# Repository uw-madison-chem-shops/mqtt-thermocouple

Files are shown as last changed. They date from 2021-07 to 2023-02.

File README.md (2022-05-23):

# MQTT thermocouple

Simple project for getting thermocouple sensors online using MQTT.

Designed to work with [mqtt.chem.wisc.edu](https://mqtt.chem.wisc.edu/).

## Repository

This is an open source hardware project licensed under the CERN Open Hardware Licence Version 2 - Permissive.
Please see the LICENSE file for the complete license.

This repository is being mirrored to several version control systems in an attempt to ensure maximum avaliability.

| name | url |
| --- | --- |
| GitHub (primary) | https://github.com/uw-madison-chem-shops/mqtt-thermocouple |
| GitLab | https://gitlab.com/uw-madison-chem-shops/mqtt-thermocouple |

## PCB

This PCB was designed using KiCAD version 5.
Refer to `mqtt-thermocouple.pdf` for schematic.
Refer to `mqtt-thermocouple.csv` for bill of materials.
PCB images generated with [tracespace](https://github.com/tracespace/tracespace) follow.




## Firmware

This project uses [micropython](https://micropython.org/), specifically [microhomie](https://github.com/microhomie/microhomie).
Refer to the "firmware" directory in this repository for detailed instructions.

## Changelog

### Unprinted

### B

#### added
- oshw logo
- github link

#### fixed
- resized holes for mounting piece
- added i2c pull up resistors

### A

#### Added
- initial design

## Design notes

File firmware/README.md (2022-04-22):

# mqtt-weather-station firmware

This project uses [micropython](https://micropython.org/), specifically [microhomie](https://github.com/microhomie/microhomie). Currently we build on microhomie-esp8266-v3.0.2, the binary is in the folder.

You must define the private information defined in `settings.py`. Copy `settings.py.example` to make a folder `settings.py` and define all relevant variables.

Run `flash.sh` to flash the board. You will need [esptool](https://github.com/espressif/esptool) and [ampy](https://github.com/scientifichackers/ampy).

We recommend an [FTDI Basic Breakout](https://www.sparkfun.com/products/9716) to physically program the ESP8266.

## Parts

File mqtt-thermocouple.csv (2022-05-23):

Source: | /home/blaise/source/uw-madison-chem-shops/mqtt-thermocouple/kicad/mqtt-thermocouple.kicad_sch
Date: | Mon 23 May 2022 12:01:26 PM CDT
Tool: | Eeschema 6.0.5+dfsg-1
Generator: | /usr/share/kicad/plugins/bom_csv_grouped_by_value_with_fp.py
Component Count: | 32
Ref | Qnty | Value | Cmp name | Footprint | Description | Vendor
A1, | 1 | Adafruit_HUZZAH_ESP8266_breakout | Adafruit_HUZZAH_ESP8266_breakout | Module:Adafruit_HUZZAH_ESP8266_breakout | 32-bit microcontroller module with WiFi
C1, | 1 | 100u | CP1 | Capacitor_THT:CP_Radial_Tantal_D7.0mm_P2.50mm
C2, | 1 | 10u | C | Capacitor_SMD:C_1206_3216Metric_Pad1.33x1.80mm_HandSolder | Unpolarized capacitor
C3, | 1 | 22u | C | Capacitor_SMD:C_1206_3216Metric_Pad1.33x1.80mm_HandSolder | Unpolarized capacitor
C4, C5, | 2 | 1u | C | Capacitor_SMD:C_1206_3216Metric_Pad1.33x1.80mm_HandSolder | Unpolarized capacitor
C6, | 1 | 100n | C | Capacitor_SMD:C_1206_3216Metric_Pad1.33x1.80mm_HandSolder | Unpolarized capacitor
C7, | 1 | 20p | C | Capacitor_SMD:C_1206_3216Metric_Pad1.33x1.80mm_HandSolder | Unpolarized capacitor
D1, D2, | 2 | LED | LED | LED_SMD:LED_1206_3216Metric_Pad1.42x1.75mm_HandSolder | Light emitting diode
D3, D4, D5, D6, | 4 | ACSC02-41SURKWA-F01 | ACSC02-41SURKWA-F01 | footprints:ACSC02-41SURKWA-F01
J1, | 1 | Barrel_Jack | Barrel_Jack | Connector_BarrelJack:BarrelJack_Horizontal | DC Barrel Jack
PS1, | 1 | VXO7805-500-M | VXO7805-500-M | CONV_VXO7805-500-M
Q1, Q2, | 2 | 2N7000 | Q_NMOS_GSD | Package_TO_SOT_SMD:SOT-23_Handsoldering | N-MOSFET transistor, gate/source/drain
R1, R2, | 2 | 1k | R_US | Resistor_SMD:R_1206_3216Metric_Pad1.30x1.75mm_HandSolder | Resistor, US symbol
R3, | 1 | 100k | R_US | Resistor_SMD:R_1206_3216Metric_Pad1.30x1.75mm_HandSolder | Resistor, US symbol
R4, R7, R8, R10, | 4 | 4.7k | R_US | Resistor_SMD:R_1206_3216Metric_Pad1.30x1.75mm_HandSolder | Resistor, US symbol
R5, | 1 | 470k | R_US | Resistor_SMD:R_1206_3216Metric_Pad1.30x1.75mm_HandSolder | Resistor, US symbol
R6, R9, | 2 | 1M | R_US | Resistor_SMD:R_1206_3216Metric_Pad1.30x1.75mm_HandSolder | Resistor, US symbol
TC1, | 1 | Thermocouple | Thermocouple | footprints:K1X-FEMX-CON-FP-X-PCCX | Thermocouple
U1, | 1 | MCP9600-E_MX | MCP9600-E_MX | footprints:MX
U2, | 1 | CD4060BM96 | CD4060BM96 | Package_SO:SOIC-16_3.9x9.9mm_P1.27mm
U3, | 1 | MAX6951 | MAX6951 | Package_SO:QSOP-16_3.9x4.9mm_P0.635mm

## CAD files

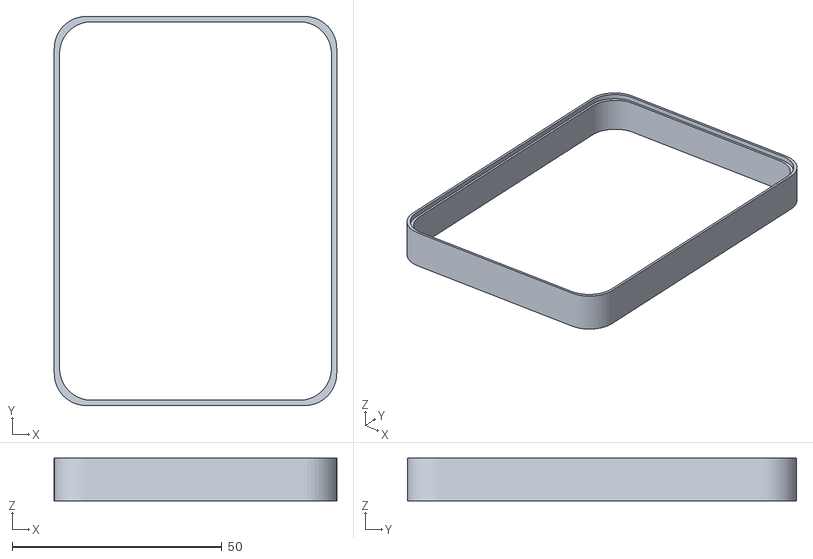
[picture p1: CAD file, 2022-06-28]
adapter-plate/potting-bracket.stl
67.3 x 92.7 x 10.2

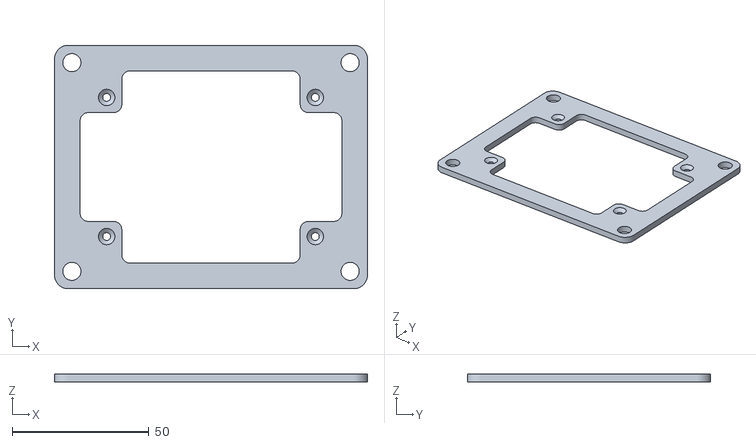
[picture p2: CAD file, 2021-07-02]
adapter-plate/adapter-plate.stl
114.3 x 88.9 x 3.00

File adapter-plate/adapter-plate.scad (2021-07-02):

$fn=50;
inch = 25.4;

module roundedRect(size, radius)
{
        x = size[0];
        y = size[1];
        z = size[2];

        linear_extrude(height=z)
        hull()
        {
                // place 4 circles in the corners, with the given radius
                translate([(-x/2)+radius, (-y/2)+radius, 0])
                circle(r=radius);

                translate([(x/2)-radius, (-y/2)+radius, 0])
                circle(r=radius);

                translate([(-x/2) + radius, (y/2)-radius, 0])
                circle(r=radius);

                translate([(x/2)-radius, (y/2)-radius, 0])
                circle(r=radius);
        }

}

module counterSunk(position, radius)
{
union()
    {
     translate(position)
     union()
        {
     cylinder(3, radius, radius, 8, center=false);
     cylinder(3, 0, 3, center=false);
        }
    }
    
}

difference()
{
roundedRect([4.5*inch, 3.5*inch, 3], 5, center=false);

translate([-4*inch/2, -3*inch/2, 0])
cylinder(3, 0.13*inch, 0.13*inch, 8, center=false);
    
translate([-4*inch/2, 3*inch/2, 0])
cylinder(3, 0.13*inch, 0.13*inch, 8, center=false);
    
translate([4*inch/2, -3*inch/2, 0])
cylinder(3, 0.13*inch, 0.13*inch, 8, center=false);
    
translate([4*inch/2, 3*inch/2, 0])
cylinder(3, 0.13*inch, 0.13*inch, 8, center=false);

counterSunk([3*inch/2, 2*inch/2, 0], 0.056*inch);
counterSunk([-3*inch/2, 2*inch/2, 0], 0.056*inch);
counterSunk([3*inch/2, -2*inch/2, 0], 0.056*inch);
counterSunk([-3*inch/2, -2*inch/2, 0], 0.056*inch);



linear_extrude(height=5)
offset(r=3){
offset(r=-6){
union(){
square([4*inch,1.8*inch], center=true);
square([2.8*inch,3*inch], center=true);
}
}
}
}

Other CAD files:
adapter-plate/potting-bracket.scad

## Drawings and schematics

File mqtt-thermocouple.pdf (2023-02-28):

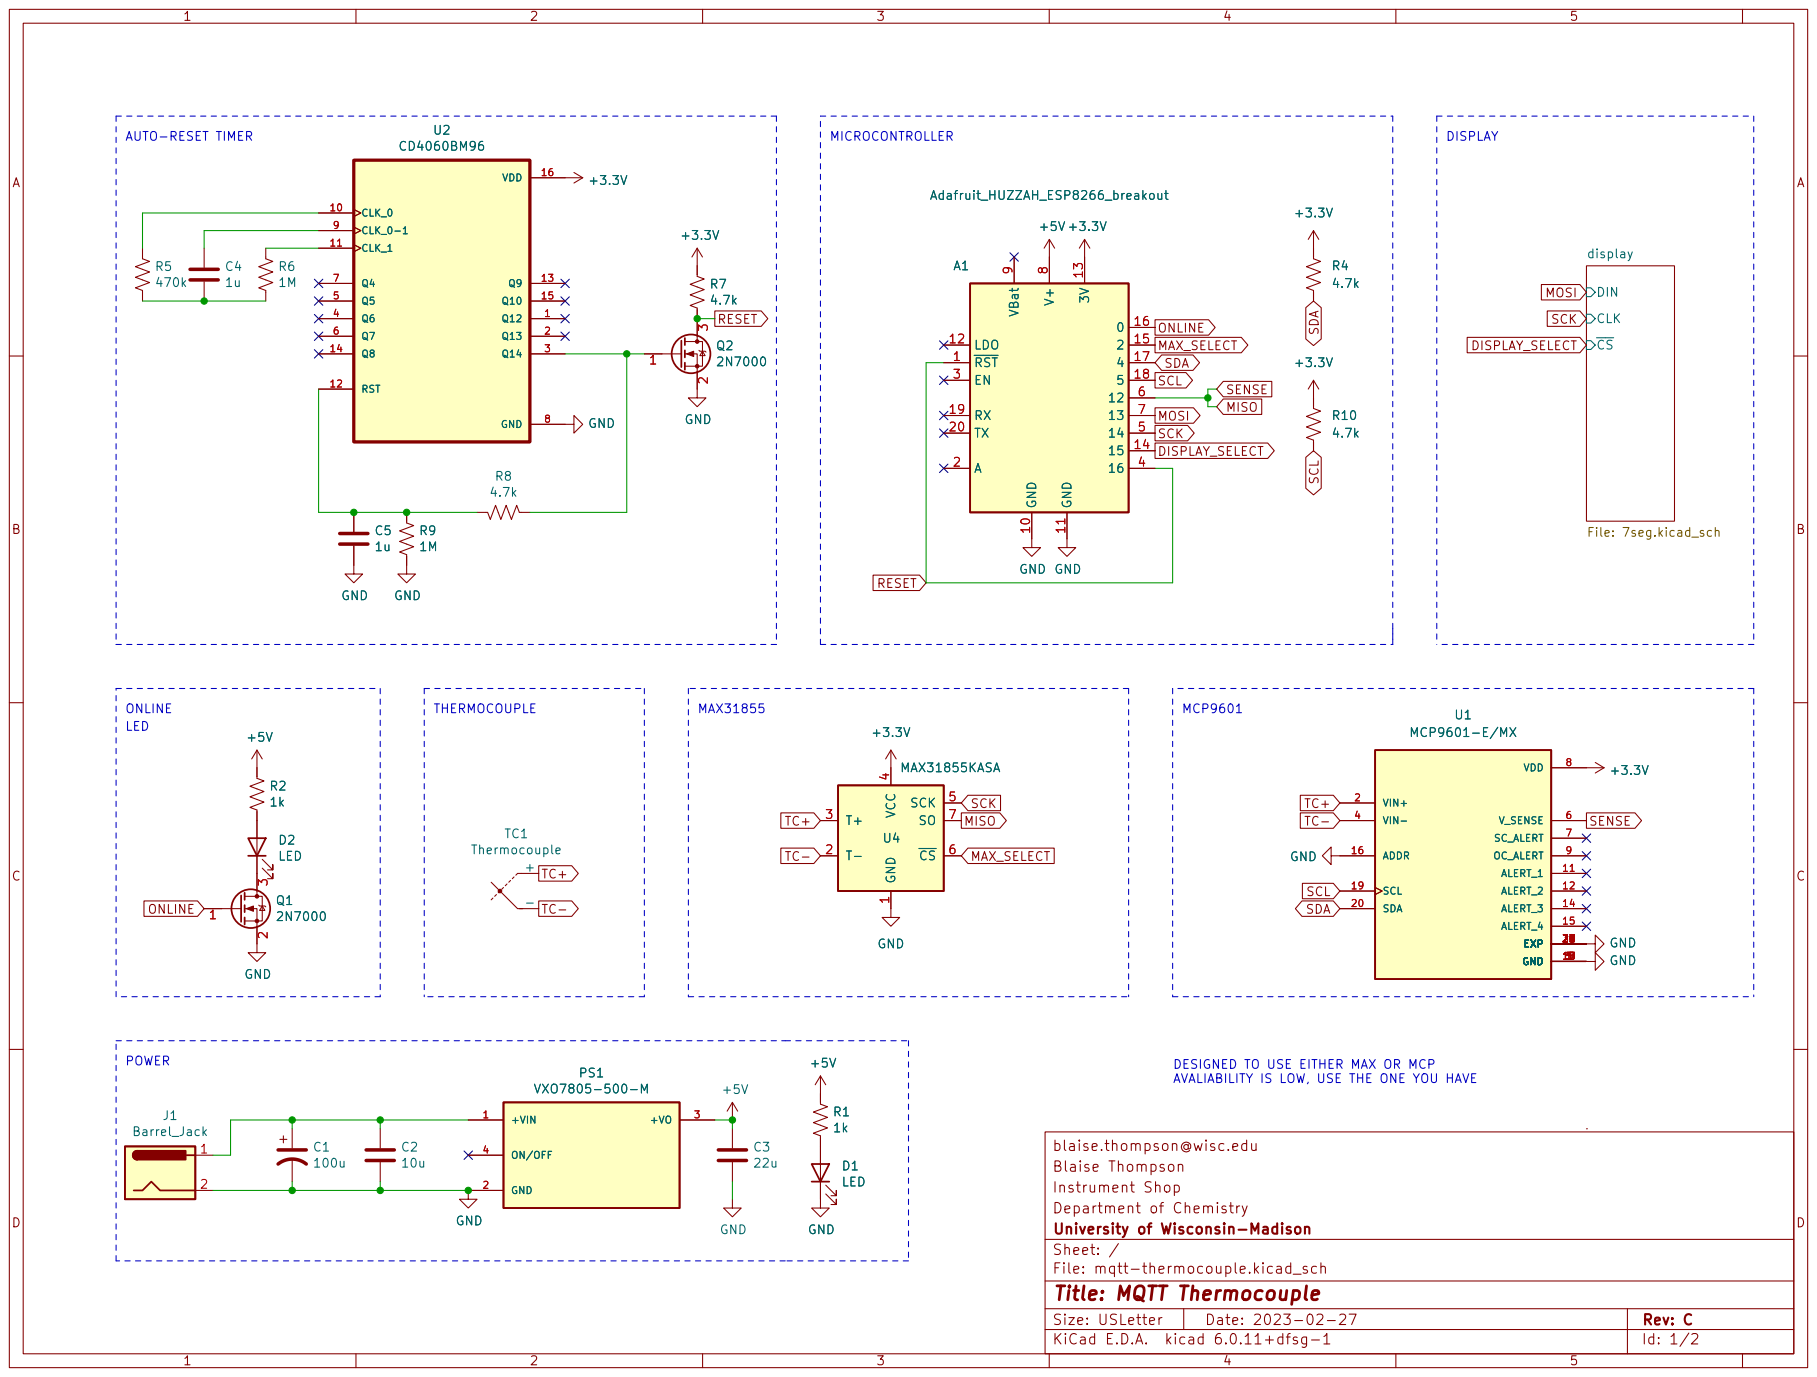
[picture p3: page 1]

4 SCK 5 ~{CS}6 SO 7 U4 MAX31855KASA GND GND

4 SCK 5 ~{CS}6 SO 7 GND

AVALIABILITY IS LOW, USE THE ONE YOU HAVE

blaise.thompson@wisc.edu

Id: 1/2 Title: MQTT Thermocouple

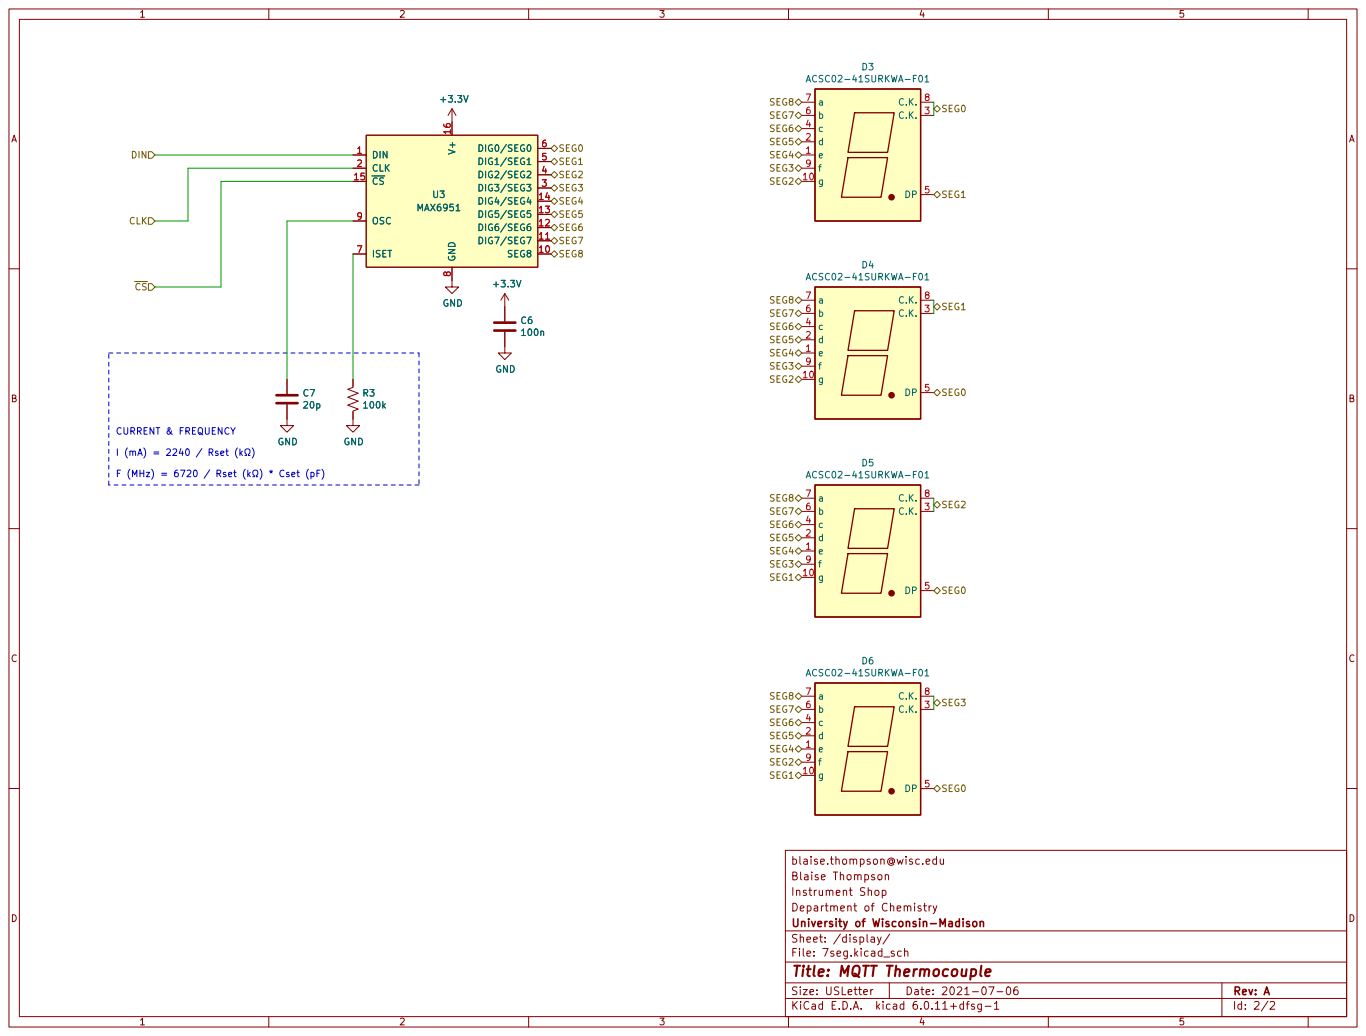
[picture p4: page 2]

File: 7seg.kicad_sch Sheet: /display/
Id: 2/2 Title: MQTT Thermocouple

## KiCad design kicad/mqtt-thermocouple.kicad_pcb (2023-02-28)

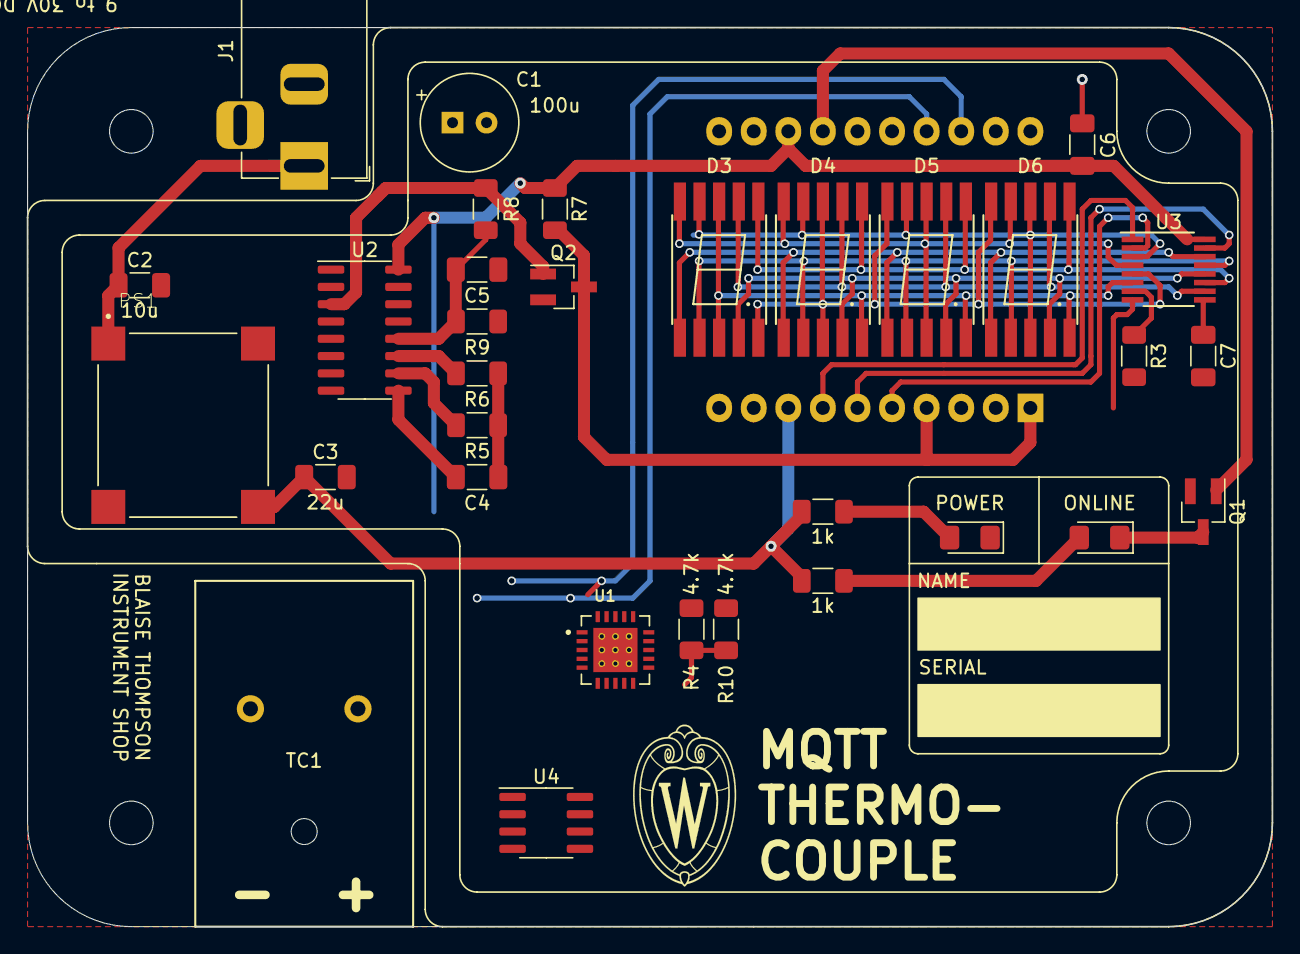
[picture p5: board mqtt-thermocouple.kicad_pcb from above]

Board: 2 copper layers, 91.4 x 66.0 mm, 33 parts (1 on the bottom side), 33 nets.

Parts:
A1: Adafruit_HUZZAH_ESP8266_breakout
C1: 100u; CP_Radial_Tantal_D7.0mm_P2.50mm
C2: 10u; C_1206_3216Metric_Pad1.33x1.80mm_HandSolder
C3: 22u; C_1206_3216Metric_Pad1.33x1.80mm_HandSolder
C4, C5: 1u; C_1206_3216Metric_Pad1.33x1.80mm_HandSolder
C6: 100n; C_1206_3216Metric_Pad1.33x1.80mm_HandSolder
C7: 20p; C_1206_3216Metric_Pad1.33x1.80mm_HandSolder
D1, D2: LED; LED_1206_3216Metric_Pad1.42x1.75mm_HandSolder
D3, D4, D5, D6: ACSC02-41SURKWA-F01
J1: Barrel_Jack; BarrelJack_Horizontal
PS1: VXO7805-500-M; CONV_VXO7805-500-M
Q1, Q2: 2N7000; SOT-23_Handsoldering
R1, R2: 1k; R_1206_3216Metric_Pad1.30x1.75mm_HandSolder
R3: 100k; R_1206_3216Metric_Pad1.30x1.75mm_HandSolder
R4, R7, R8, R10: 4.7k; R_1206_3216Metric_Pad1.30x1.75mm_HandSolder
R5: 470k; R_1206_3216Metric_Pad1.30x1.75mm_HandSolder
R6, R9: 1M; R_1206_3216Metric_Pad1.30x1.75mm_HandSolder
TC1: Thermocouple; K1X-FEMX-CON-FP-X-PCCX
U1: MCP9600-E_MX; MX
U2: CD4060BM96; SOIC-16_3.9x9.9mm_P1.27mm
U3: MAX6951; QSOP-16_3.9x4.9mm_P0.635mm
U4: MAX31855KASA; SOIC-8_3.9x4.9mm_P1.27mm

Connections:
+3V3: A1.13 (3V), C6.1, R4.1, R7.1, R10.1, U1.8 (VDD), U2.16 (VDD), U3.16 (V+)
+5V: A1.8 (V+), C3.1, PS1.3 (+VO), R1.1, R2.1
/display/SEG0: D3.3 (C.K.), D3.8 (C.K.), D4.5 (DP), D5.5 (DP), D6.5 (DP), U3.6 (DIG0/SEG0)
/display/SEG1: D3.5 (DP), D4.3 (C.K.), D4.8 (C.K.), D5.10 (g), D6.10 (g), U3.5 (DIG1/SEG1)
/display/SEG2: D3.10 (g), D4.10 (g), D5.3 (C.K.), D5.8 (C.K.), D6.9 (f), U3.4 (DIG2/SEG2)
/display/SEG3: D3.9 (f), D4.9 (f), D5.9 (f), D6.3 (C.K.), D6.8 (C.K.), U3.3 (DIG3/SEG3)
/display/SEG4: D3.1 (e), D4.1 (e), D5.1 (e), D6.1 (e), U3.14 (DIG4/SEG4)
/display/SEG5: D3.2 (d), D4.2 (d), D5.2 (d), D6.2 (d), U3.13 (DIG5/SEG5)
/display/SEG6: D3.4 (c), D4.4 (c), D5.4 (c), D6.4 (c), U3.12 (DIG6/SEG6)
/display/SEG7: D3.6 (b), D4.6 (b), D5.6 (b), D6.6 (b), U3.11 (DIG7/SEG7)
/display/SEG8: D3.7 (a), D4.7 (a), D5.7 (a), D6.7 (a), U3.10 (SEG8)
/display/~CS: A1.6 (12), U3.15 (~CS)
GND: A1.10 (GND), A1.11 (GND), C1.2, C2.2, C3.2, C5.2, C6.2, C7.2, D1.1 (K), J1.2, PS1.2 (GND), Q1.2 (S), Q2.2 (S), R3.2, R9.2, U1.1 (GND), U1.3 (GND), U1.5 (GND), U1.6 (GND), U1.7 (GND), U1.9 (GND), U1.10 (GND), U1.13 (GND), U1.16 (ADDR), U1.17 (GND), U1.18 (GND), U2.8 (GND), U3.8 (GND)
MOSI: A1.7 (13), U3.1 (DIN)
unnamed: A1.1 (~RST), A1.4 (16), Q2.3 (D), R7.2
unnamed: A1.16 (0), Q1.1 (G)
unnamed: C1.1, C2.1, J1.1, PS1.1 (+VIN)
unnamed: C4.1, U2.9 (CLK_0-1)
unnamed: C4.2, R5.1, R6.1
unnamed: C5.1, R8.2, R9.1, U2.12 (RST)
unnamed: C7.1, U3.9 (OSC)
unnamed: D1.2 (A), R1.2
unnamed: D2.1 (K), Q1.3 (D)
unnamed: D2.2 (A), R2.2
unnamed: Q2.1 (G), R8.1, U2.3 (Q14)
unnamed: R3.1, U3.7 (ISET)
unnamed: R5.2, U2.10 (CLK_0)
unnamed: R6.2, U2.11 (CLK_1)
unnamed: TC1.1 (+), U1.2 (VIN+)
unnamed: TC1.2 (-), U1.4 (VIN-)
SCK: A1.5 (14), U3.2 (CLK)
SCL: A1.18 (5), R10.2, U1.19 (SCL)
SDA: A1.17 (4), R4.2, U1.20 (SDA)

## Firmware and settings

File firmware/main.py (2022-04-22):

import settings

import sys
import machine
from machine import Pin, I2C, SPI
import network
import time
import struct

import mqtt_as
mqtt_as.MQTT_base.DEBUG = True



from homie.constants import FALSE, TRUE, BOOLEAN, FLOAT, STRING
from homie.device import HomieDevice
from homie.node import HomieNode
from homie.property import HomieNodeProperty

from uasyncio import get_event_loop, sleep_ms


from max9651 import MAX9651



def temp_c(byteData):
    # Taken from MCP9600 Datasheet:
    # Temperature >= 0°C
    # TΔ = (UpperByte x 16 + LowerByte / 16)
    # Temperature < 0°C
    # TΔ = (UpperByte x 16 + LowerByte / 16) - 4096

    temp = (byteData[0] * 16 + byteData[1] / 16)
    value = byteData[0] << 8 | byteData[1]

    if value & 0x1000:
        temp -= 4096.0
    return temp



class TemperatureSensor(HomieNode):

    def __init__(self, name="thermocouple", device=None):
        super().__init__(id="thermocouple", name=name, type="sensor")
        self.device = device
        self.i2c = I2C(scl=Pin(5), sda=Pin(4))
        self.display = MAX9651()
        self.temperature = HomieNodeProperty(
            id="temperature",
            name="temperature",
            unit="°C",
            settable=False,
            datatype=FLOAT,
            default=0,
        )
        self.add_property(self.temperature)
        self.uptime = HomieNodeProperty(
            id="uptime",
            name="uptime",
            settable=False,
            datatype=STRING,
            default="PT0S"
        )
        self.add_property(self.uptime)
        self.ip = HomieNodeProperty(
            id="ip",
            name="ip",
            settable=False,
            datatype=STRING,
            default="",
        )
        self.add_property(self.ip)
        self.led = Pin(0, Pin.OUT)
        self.online_led = Pin(15, Pin.OUT)
        self.online_led.off()
        self.last_online = time.time()
        self.start = time.time()
        print("start time", self.start)
        self.measured_temps = []
        loop = get_event_loop()
        loop.create_task(self.measure_temp())
        loop.create_task(self.update_data())

    async def update_data(self):
        # wait until connected
        for _ in range(60):
            print("wait until connected")
            await sleep_ms(1_000)
            if self.device.mqtt.isconnected():
                break
        # loop forever
        while True:
            while self.device.mqtt.isconnected():
                print("update data")
                print(network.WLAN().status())
                self.last_online = time.time()
                print(1)
                self.online_led.on()
                print(2)
                self.led.value(0)  # illuminate onboard LED
                self.temperature.data = str(sum(self.measured_temps) / len(self.measured_temps))
                self.measured_temps = []
                self.uptime.data = self.get_uptime()
                self.ip.data = network.WLAN().ifconfig()[0]
                self.led.value(1)  # onboard LED off
                print("final")
                await sleep_ms(15_000)
            while not self.device.mqtt.isconnected():
                print("wait for reconnect")
                if time.time() - self.last_online > 300:   # 5 minutes
                    machine.reset()
                self.online_led.off()
                self.led.value(0)  # illuminate onboard LED
                await sleep_ms(100)
                self.led.value(1)  # onboard LED off
                await sleep_ms(1000)
            machine.reset()  # if lost connection, restart

    async def measure_temp(self):
        while True:
            temp = temp_c(self.i2c.readfrom_mem(0b0110_0000, 0b0000_0000, 2))
            print(temp)
            self.display.show(temp)
            self.measured_temps.append(temp)
            await sleep_ms(500)


    def get_uptime(self):
        diff = int(time.time() - self.start)
        out = "PT"
        # hours
        if diff // 3600:
            out += str(diff // 3600) + "H"
            diff %= 3600
        # minutes
        if diff // 60:
            out += str(diff // 60) + "M"
            diff %= 60
        # seconds
        out += str(diff) + "S"
        return out

def main():
    print("homie main")
    homie = HomieDevice(settings)
    homie.add_node(TemperatureSensor(device=homie))
    homie.run_forever()


if __name__ == "__main__":
    main()

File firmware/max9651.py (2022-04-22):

from machine import Pin, I2C, SPI
import time



class MAX9651(object):

    def __init__(self):
        self.spi = SPI(sck=Pin(14), mosi=Pin(13), miso=Pin(15), baudrate=50_000, polarity=0)
        self.cs = Pin(12, mode=Pin.OUT, value=1)
        self._write_bytes(b"\x01\xFF")  # enable decode mode
        self._write_bytes(b"\x02\x7F")  # intensity
        self._write_bytes(b"\x03\x03")  # display four digits
        self._write_bytes(b"\x04\x21")  # clear

    def show(self, num: float):
        string = "{:.1f}".format(num)
        string = ("0" * (5 - len(string))) + string
        self._write_bytes(b"\x60" + int(string[0]).to_bytes(1, "big"))
        self._write_bytes(b"\x61" + int(string[1]).to_bytes(1, "big"))
        self._write_bytes(b"\x62" + (int(string[2]) | 128).to_bytes(1, "big"))
        self._write_bytes(b"\x63" + int(string[4]).to_bytes(1, "big"))

    def _write_bytes(self, data: bytes):
        time.sleep(0.01)
        self.cs(0)
        time.sleep(0.01)
        self.spi.write(data)
        time.sleep(0.01)
        self.cs(1)
        time.sleep(0.01)

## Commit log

2021-07-02 basic schematic and incomplete layout
    [7seg.sch, adapter-plate.scad, adapter-plate.stl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]
2021-07-06 revision A
    [7seg.sch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]
2021-07-09 forgotten fill
    [mqtt-thermocouple-B_Cu.gbr, mqtt-thermocouple-B_Mask.gbr, mqtt-thermocouple-B_Paste.gbr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]
2022-04-22 tracespace rerender
